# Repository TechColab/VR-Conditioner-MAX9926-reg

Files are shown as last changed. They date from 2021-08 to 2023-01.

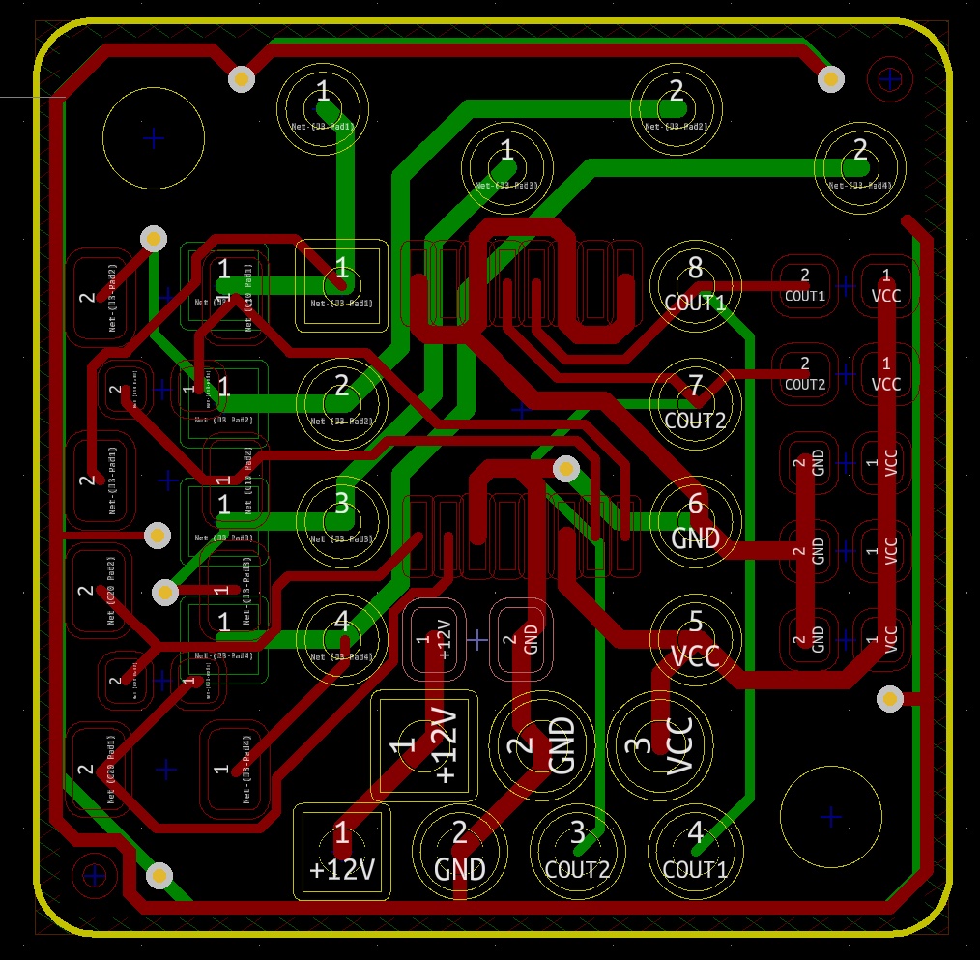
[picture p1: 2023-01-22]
PCB-Tracks.jpg

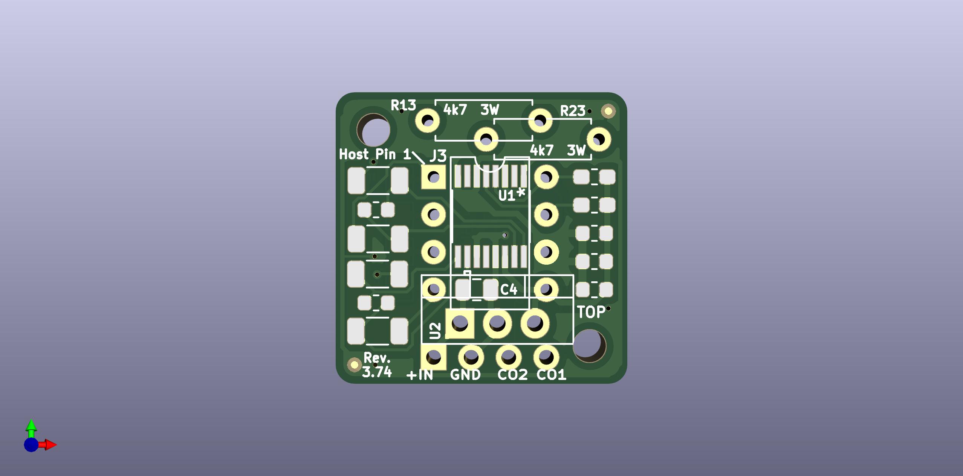
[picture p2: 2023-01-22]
VR-Conditioner-MAX9926+reg-F.jpg

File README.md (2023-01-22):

### 2023-01-22
Most significant change is to correct the Channel 1 polarity of previous version.
In practise everyone seems to try their VR pick-up in both polarities before settling on the best for their set-up.
Tidied the silkscreen a lot to improve readability. Removed component IDs from silkscreen. Still on the FAB layer.
Moved a regulator & edge pin header slightly to make soldering easier.
Re-routed traces from header pins 1 & 2 so that either could be cut if you wanted to mix VR & a piggy-backed opto-isolator.
Also update because KiCAD v6.x seems to have moved a lot of things.

### 2022-09-10
Received a batch of v3.73 boards & bench-tested using 13 year-old Crankshaft Position Sensor 7674201-01 from 2009 BMW F800R 
and a metal 'L' hook screw in a hand drill at about 1000 rpm. All OK on 5V & also on 12V with a TS78L05CT TO-92 regulator.

### 2022-08-14
Replace linear regulator with more robust choice. Move U1 & C4 to make space. Adjust all tracks as required including widening. 
Updated BOM.  I will shortly be ordering a run of these, e-mail if you're interested: TechColab.co.je [at] Gmail.con

### 2022-08-07
Added test-pads which can be used to solder directly when not using socket mount, E.g. when placing the VR conditioner as close as possible to the engine sensors in noisy environments. Improved ground plane shielding & much improved silk screen labelling. Tried to fit an official OpenSource Hardware logo but even the smallest is too big. Update to KiCAD v6.x so 3D renders now without components.  N.B. To be clear, this board is for VR only & does not support an opto-isolator option.

### 2021-02-23
I have not made & tested this design but it is barely changed from the manufacrurers data sheets or other designs.
If you make & test it then please advise.

I'm new to KiCAD so I don't know how to do some things.  Such as how to have an 8-pin set of holes without a 3D chip sitting in it.
Or how to do an 8-pin header in the shape & pin count order of a chip.

### 2021-02-24
Changed version number to 3.5 so that it reflects relative cronology from previous design.
Renamed this from Notes.txt to README.md & corrected the date above.
Added Comments to schematic, inc. single-sided design allowing 'Letter' postage!
Updated BOM in schematic to reflect readily available parts found on OctoPart.

### 2021-04-22
Goal: give the left 6 passive components some space from the edge.
Increase size/power of some SMT resistors where suggested.
Re-route COUT1 from DIP.8 to SIL.4 in green so no signal traces are by the edge.
Shift right 5 components slightly right.
Shift DIP, chip & hidden cap slightly right.
Shift left 6 components slightly right.
Re-route left 6 components to avoid side swapping.
Ensure GND plane encircles everything with a via in each corner.
Tidy with some symetry.
Ensure all 'thin' traces are 0.20mm (up from 0.16)

### 2021-08-16
Move to it's own project to reflect that Speeduino main project has dropped all VRs.
Re-applied logical resistor numbering.  Bumped schematic v to 3.7 to match PCB.

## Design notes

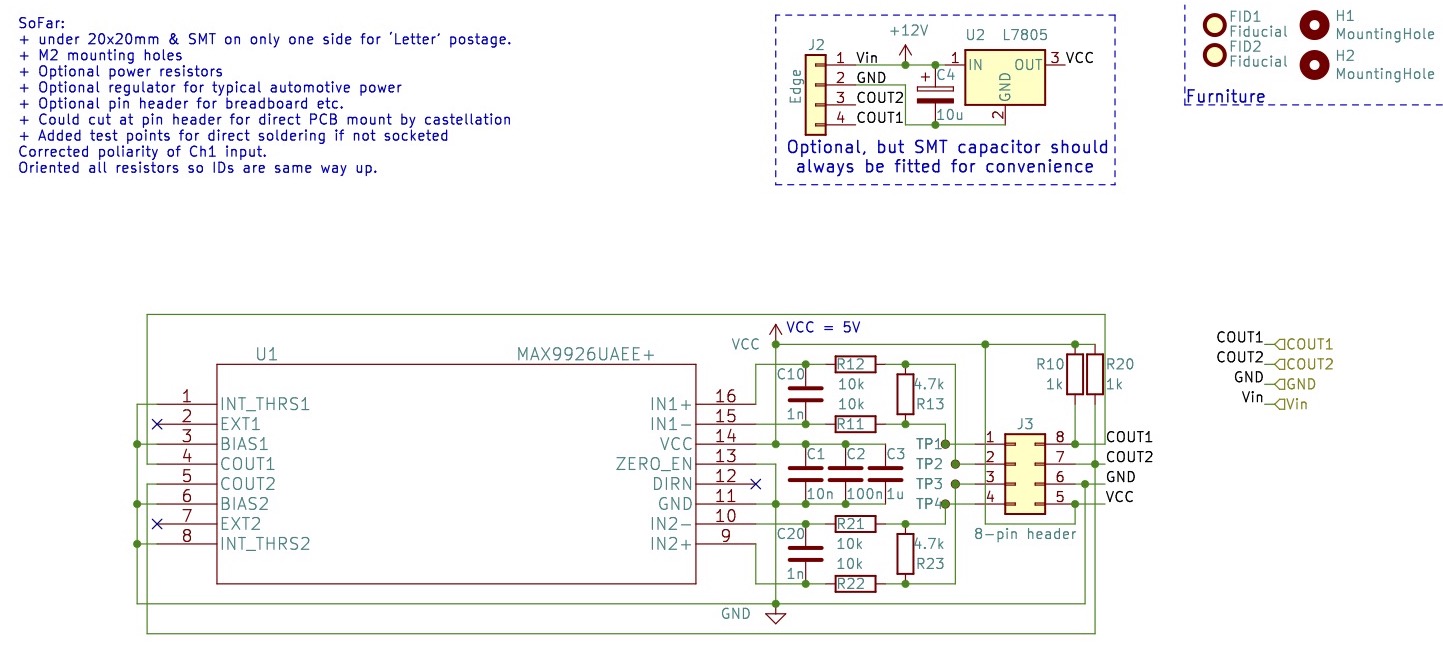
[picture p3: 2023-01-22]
Schematic.jpg

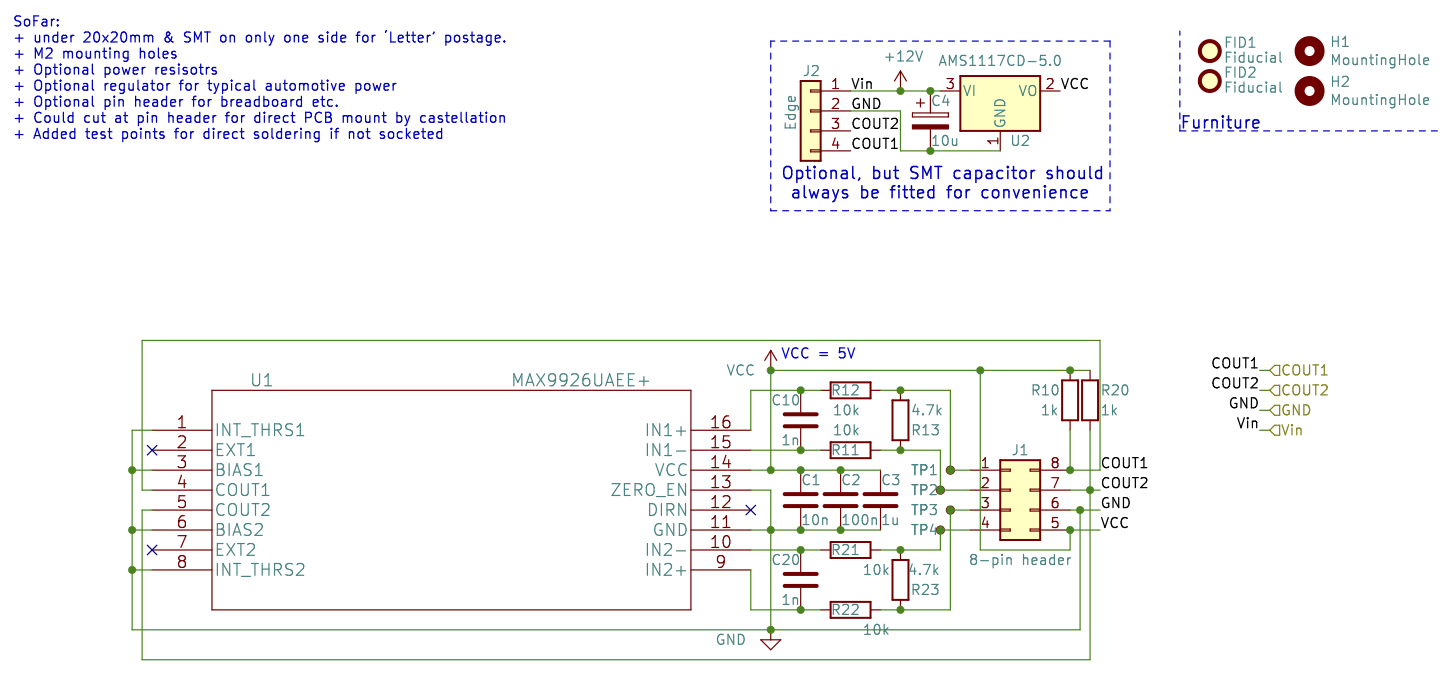
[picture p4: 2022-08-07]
Schematic.png

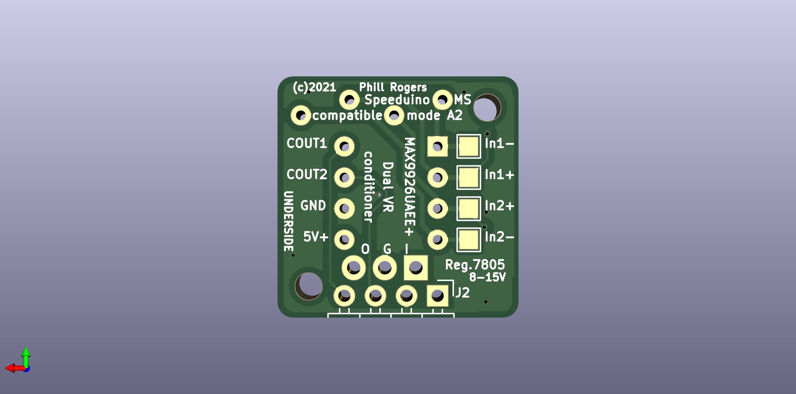
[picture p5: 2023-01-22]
VR-Conditioner-MAX9926+reg-B.jpg

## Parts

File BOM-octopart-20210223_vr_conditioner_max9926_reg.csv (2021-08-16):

Qty | Line Item | Manufacturer | MPN | Octopart URL | Schematic Reference | Internal Part Number | Description | Lifecycle Status | Lead Time | RoHS | Total Qty (@ Batch Size: 1) | SKU | SKU | SKU | SKU | Packaging | Packaging | Packaging | Packaging | Unit Price (@ Batch Size: 1) | Unit Price (@ Batch Size: 1) | Unit Price (@ Batch Size: 1) | Unit Price (@ Batch Size: 1) | In Stock | In Stock | In Stock | In Stock | MOQ | MOQ | MOQ | MOQ | URL | URL | URL | URL | Distributor [Lowest Price (Overall)] | SKU [Lowest Price (Overall)] | Packaging [Lowest Price (Overall)] | Unit Price (@ Batch Size: 1) [Lowest Price (Overall)] | Line Total [Lowest Price (Overall)] | Batch Total [Lowest Price (Overall)] | In Stock [Lowest Price (Overall)] | MOQ [Lowest Price (Overall)] | URL [Lowest Price (Overall)] | Notes
 |  |  |  |  |  |  |  |  |  |  |  | Digi-Key | Future Electronics | Mouser | RS Components | Digi-Key | Future Electronics | Mouser | RS Components | Digi-Key | Future Electronics | Mouser | RS Components | Digi-Key | Future Electronics | Mouser | RS Components | Digi-Key | Future Electronics | Mouser | RS Components | Digi-Key | Future Electronics | Mouser | RS Components
1 | GRM1857U1A103JA44D | Murata | GRM1857U1A103JA44D | https://octopart.com/grm1857u1a103ja44d-murata-17754272 |  |  |  | Production (Last Updated: 2 weeks ago) | 23w | Compliant | 1 | 490-8269-1-ND | 1117428 | 81-GRM1857U1A103JA4D |  | Cut Tape | Cut Tape | Tape & Reel |  | 0.15622662 | 0.159777225 | 0.17753025 |  | 24842 | 8000 | 6230 |  | 1 | 1 | 1 |  | https://octopart.com/click/track?country=JE&ct=offers&ppid=17754272&sid=459&sig=0a4da8a&vpid=88253296&ai4=706 | https://octopart.com/click/track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 | https://octopart.com/click/track?country=JE&ct=offers&ppid=17754272&sid=2401&sig=0942290&vpid=37708184&ai4=706 |  | Arrow Electronics | GRM1857U1A103JA44D | Cut Tape | 0.1077253557 | 0.1077253557 | 0.1077253557 | 1 | 1 | https://octopart.com/click/track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
2 | CRCW06031K00FKEAHP | Vishay | CRCW06031K00FKEAHP | https://octopart.com/crcw06031k00fkeahp-vishay-42634138 |  |  |  |  | 24w | Compliant | 2 | 541-1.00KSCT-ND | 7110920 | 71-CRCW06031K00FKEAH | 8206776 | Cut Tape | Cut Tape | Tape & Reel |  | 0.12072057000000001 | 0.104387787 | 0.12072057000000001 |  | 205723 | 16210 | 69615 | 2125 | 1 | 1 | 1 | 25 | https://octopart.com/click/track?country=JE&ct=offers&ppid=42634138&sid=459&sig=04dce86&vpid=115677389&ai4=706 | https://octopart.com/click/track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 | https://octopart.com/click/track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 | https://octopart.com/click/track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 | Farnell | 1738905 | Cut Tape | 0.0412 | 0.0824 | 0.0824 | 32145 | 1 | https://octopart.com/click/track?country=JE&ct=offers&ppid=42634138&sid=819&sig=05fe86e&vpid=250080956&ai4=706
4 | CRCW060310K0FKEAHP | Vishay | CRCW060310K0FKEAHP | https://octopart.com/crcw060310k0fkeahp-vishay-42634028 |  |  |  |  | 24w | Compliant | 4 | 541-10.0KSCT-ND | 6103726 | 71-CRCW060310K0FKEAH | 8206742 | Cut Tape | Cut Tape | Tape & Reel |  | 0.12072057000000001 | 0.104387787 | 0.12072057000000001 |  | 84206 | 65036 | 112208 | 2550 | 1 | 1 | 1 | 25 | https://octopart.com/click/track?country=JE&ct=offers&ppid=42634028&sid=459&sig=0828559&vpid=115262443&ai4=706 | https://octopart.com/click/track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 | https://octopart.com/click/track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 | https://octopart.com/click/track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 | Newark | 68R2991 | Cut Tape | 0.017753025000000002 | 0.07101210000000001 | 0.07101210000000001 | 10760 | 1 | https://octopart.com/click/track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
1 | MAX9926UAEE+ | Maxim Integrated | MAX9926UAEE+ | https://octopart.com/max9926uaee%2B-maxim+integrated-42513566 |  |  |  | Production (Last Updated: 1 month ago) | 6w | Compliant | 1 | MAX9926UAEE+-ND | 3086399 | 700-MAX9926UAEE | 1901381 | Tube | Tube | Tube |  | 4.86432885 |  | 6.44789868 | 4.98 | 1069 | 100 | 299 | 0 | 1 | 100 | 1 | 1 | https://octopart.com/click/track?country=JE&ct=offers&ppid=42513566&sid=459&sig=0fd0a9b&vpid=115650128&ai4=706 | https://octopart.com/click/track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 | https://octopart.com/click/track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 | https://octopart.com/click/track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 | Newark | 73Y6635 |  | 4.73650707 | 4.73650707 | 4.73650707 | 10 | 1 | https://octopart.com/click/track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
1 | GCM188R71C105KA64D | Murata | GCM188R71C105KA64D | https://octopart.com/gcm188r71c105ka64d-murata-13159598 |  |  |  | Production (Last Updated: 2 weeks ago) | 27w | Compliant | 1 | 490-5241-1-ND | 7025260 | 81-GCM188R71C105K64D | 7900562 | Cut Tape | Cut Tape | Tape & Reel |  | 0.15622662 | 0.152676015 | 0.15622662 |  | 272359 | 2118 | 0 | 11400 | 1 | 1 | 1 | 25 | https://octopart.com/click/track?country=JE&ct=offers&ppid=13159598&sid=459&sig=065a155&vpid=34232850&ai4=706 | https://octopart.com/click/track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 | https://octopart.com/click/track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 | https://octopart.com/click/track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 | Arrow Electronics | GCM188R71C105KA64D | Cut Tape | 0.1297391067 | 0.1297391067 | 0.1297391067 | 52386 | 1 | https://octopart.com/click/track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
1 | GRM21BR61E106MA73L | Murata | GRM21BR61E106MA73L | https://octopart.com/grm21br61e106ma73l-murata-46693545 |  |  |  | Production (Last Updated: 2 weeks ago) | 29w | Compliant | 1 | 490-10748-1-ND | 3104124 | 81-GRM21BR61E106MA3L | 1726799 | Cut Tape | Cut Tape | Tape & Reel |  | 0.17753025 | 0.173979645 | 0.18463146 |  | 169134 | 22568 | 63443 | 700 | 1 | 1 | 1 | 50 | https://octopart.com/click/track?country=JE&ct=offers&ppid=46693545&sid=459&sig=0e7381d&vpid=210890997&ai4=706 | https://octopart.com/click/track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 | https://octopart.com/click/track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 | https://octopart.com/click/track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 | Arrow Electronics | GRM21BR61E106MA73L | Cut Tape | 0.1290289857 | 0.1290289857 | 0.1290289857 | 18282 | 1 | https://octopart.com/click/track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
2 | GRM1885C1H102JA01D | Murata | GRM1885C1H102JA01D | https://octopart.com/grm1885c1h102ja01d-murata-196169 |  |  |  | Production (Last Updated: 2 weeks ago) | 29w | Compliant | 2 | 490-1451-1-ND | 5104092 | 81-GRM39C102J50 | 7235795 | Cut Tape | Cut Tape | Tape & Reel |  | 0.07101210000000001 | 0.0102257424 | 0.07101210000000001 |  | 0 | 2890 | 845260 | 5800 | 1 | 1 | 1 | 200 | https://octopart.com/click/track?c=1&country=JE&ct=offers&ppid=196169&sid=459&sig=0c67cea&vpid=1086114&ai4=706 | https://octopart.com/click/track?country=JE&ct=offers&ppid=196169&sid=2454&sig=06c4930&vpid=495870445&ai4=706 | https://octopart.com/click/track?country=JE&ct=offers&ppid=196169&sid=2401&sig=0c58fdf&vpid=37712468&ai4=706 | https://octopart.com/click/track?country=JE&ct=offers&ppid=196169&sid=10022&sig=0888f0c&vpid=199072014&ai4=706 | Future Electronics | 5104092 | Cut Tape | 0.0102257424 | 0.0204514848 | 0.0204514848 | 2890 | 1 | https://octopart.com/click/track?country=JE&ct=offers&ppid=196169&sid=2454&sig=06c4930&vpid=495870445&ai4=706
1 | GCJ188R71C104KA01D | Murata | GCJ188R71C104KA01D | https://octopart.com/gcj188r71c104ka01d-murata-21222040 |  |  |  | Production (Last Updated: 2 weeks ago) | 27w | Compliant | 1 | 490-5796-1-ND | 6113232 | 81-GCJ188R71C104KA1D |  | Cut Tape | Cut Tape | Tape & Reel |  | 0.19173267000000002 | 0.188182065 | 0.17042904 |  | 38484 | 1000 | 178383 |  | 1 | 1 | 1 |  | https://octopart.com/click/track?country=JE&ct=offers&ppid=21222040&sid=459&sig=0e464ea&vpid=44469513&ai4=706 | https://octopart.com/click/track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 | https://octopart.com/click/track?country=JE&ct=offers&ppid=21222040&sid=2401&sig=02bb046&vpid=47654983&ai4=706 |  | Mouser | 81-GCJ188R71C104KA1D | Tape & Reel | 0.17042904 | 0.17042904 | 0.17042904 | 178383 | 1 | https://octopart.com/click/track?country=JE&ct=offers&ppid=21222040&sid=2401&sig=02bb046&vpid=47654983&ai4=706

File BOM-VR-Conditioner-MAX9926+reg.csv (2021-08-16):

Reference | Value | Footprint | Datasheet | Critical | Description | MFG Name | MFG Part Num | Package JEDEC ID
FID1 | Fiducial | Fiducial:Fiducial_0.5mm_Mask1mm | ~
FID2 | Fiducial | Fiducial:Fiducial_0.5mm_Mask1mm | ~
U1 | MAX9926UAEE+ | MAX9926UAEE+:MAX9926UAEE&plus_ | https://datasheet.octopart.com/MAX9926UAEE%2B-Maxim-Integrated-datasheet-11046290.pdf | Yes | MAX9926 Series 10 mA Differential Input Logic Output Sensor Interface -SSOP-16 | Maxim Integrated | MAX9926UAEE+ | SSOP-16
C1 | 10n | Capacitor_SMD:C_0603_1608Metric | ~ |  | 10 V ±5% Tolerance U2J Multilayer Ceramic Capacitor | Murata Murata | GRM1857U1A103JA44D | 0603_1608Metric
C2 | 100n | Capacitor_SMD:C_0603_1608Metric | ~ |  | Ceramic 0.1uF 16V X7R 10% Pad SMD 0603 Soft Termination 125C Automotive T/R | Murata | GCJ188R71C104KA01D | 0603_1608Metric
C3 | 1u | Capacitor_SMD:C_0603_1608Metric | ~ |  | 16V ±10% Tolerance X7R Surface Mount Multilayer Ceramic Capacitor | Murata | GCM188R71C105KA64D | 0603_1608Metric
C20 | 1n | Capacitor_SMD:C_0603_1608Metric | ~ |  | 1000 pF 50 V ±5 % Tolerance C0G SMT Multilayer Ceramic Capacitor | Murata | GRM1885C1H102JA01D | 0603_1608Metric
C10 | 1n | Capacitor_SMD:C_0603_1608Metric | ~ |  | 1000 pF 50 V ±5 % Tolerance C0G SMT Multilayer Ceramic Capacitor | Murata | GRM1885C1H102JA01D | 0603_1608Metric
R22 | 10k | Resistor_SMD:R_0603_1608Metric_Pad1.05x0.95mm_HandSolder | ~ |  |  | Yageo | RC1206FR-7W10KL | Resistor_SMD:R_1206_3216Metric
R21 | 10k | Resistor_SMD:R_0603_1608Metric_Pad1.05x0.95mm_HandSolder | ~ |  |  | Yageo | RC1206FR-7W10KL | Resistor_SMD:R_1206_3216Metric
R11 | 10k | Resistor_SMD:R_0603_1608Metric_Pad1.05x0.95mm_HandSolder | ~ |  |  | Yageo | RC1206FR-7W10KL | Resistor_SMD:R_1206_3216Metric
R12 | 10k | Resistor_SMD:R_0603_1608Metric_Pad1.05x0.95mm_HandSolder | ~ |  |  | Yageo | RC1206FR-7W10KL | Resistor_SMD:R_1206_3216Metric
R13 | 4.7k | Resistor_THT:R_Axial_DIN0207_L6.3mm_D2.5mm_P7.62mm_Horizontal | ~ | DoNoPlace. User option | 3W, 5%
J1 | 8-pin header | Package_DIP:DIP-8_W7.62mm | ~
R20 | 1k | Resistor_SMD:R_0603_1608Metric_Pad1.05x0.95mm_HandSolder | ~ |  | Thick Film; +/-1% 0.2W | Vishay | CRCW06031K00FKEAHP | 0603_1608Metric
R10 | 1k | Resistor_SMD:R_0603_1608Metric_Pad1.05x0.95mm_HandSolder | ~ |  | Thick Film; +/-1% 0.2W | Vishay | CRCW06031K00FKEAHP | 0603_1608Metric
H1 | MountingHole | MountingHole:MountingHole_2.2mm_M2 | ~
H2 | MountingHole | MountingHole:MountingHole_2.2mm_M2 | ~
C4 | 10u | Capacitor_SMD:C_0805_2012Metric | ~ |  | 25 V 10 uF ±20% Tolerance X5R Multilayer Ceramic Capacitor | Murata | GRM21BR61E106MA73L | 0805_2012Metric
R23 | 4.7k | Resistor_THT:R_Axial_DIN0207_L6.3mm_D2.5mm_P7.62mm_Horizontal | ~ | DoNoPlace. User option | 3W, 5%
U2 | AMS1117CD-5.0 | Package_TO_SOT_THT:TO-92_Inline_Wide | http://www.advanced-monolithic.com/pdf/ds1117.pdf | DoNoPlace. User option | 1A Low Dropout Voltage Regulator | Advanced Monolithic Systems | AMS1117-5.0 | TO92 inline wide
J2 | Edge | Connector_PinHeader_2.54mm:PinHeader_1x04_P2.54mm_Horizontal | ~ | DoNoPlace. User option

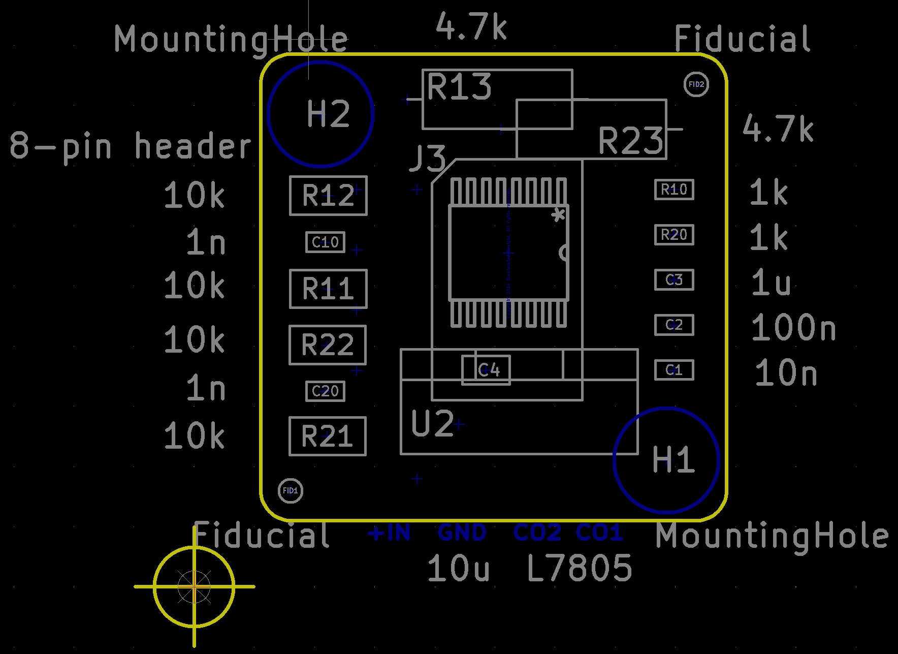
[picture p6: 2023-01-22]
Component layout.jpg

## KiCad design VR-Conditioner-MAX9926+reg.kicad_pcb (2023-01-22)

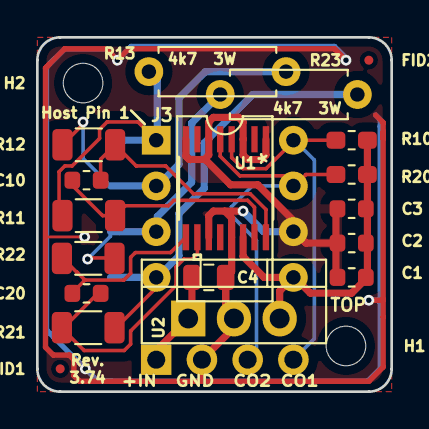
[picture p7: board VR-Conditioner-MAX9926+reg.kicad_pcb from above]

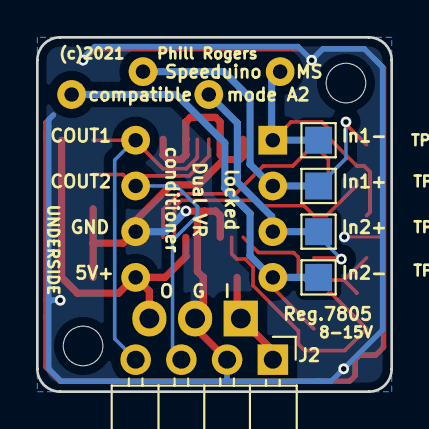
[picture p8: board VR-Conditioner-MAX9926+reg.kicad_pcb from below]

Board: 2 copper layers, 19.7 x 19.7 mm, 26 parts (5 on the bottom side), 13 nets.

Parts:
C1: 10n; C_0603_1608Metric
C2: 100n; C_0603_1608Metric
C3: 1u; C_0603_1608Metric
C4: 10u; C_0805_2012Metric
C10, C20: 1n; C_0603_1608Metric
FID1, FID2: Fiducial; Fiducial_0.5mm_Mask1mm
H1, H2: MountingHole; MountingHole_2.2mm_M2
J2: Edge; PinHeader_1x04_P2.54mm_Horizontal
J3: 8-pin header; DIP-8_W7.62mm
R10, R20: 1k; R_0603_1608Metric_Pad1.05x0.95mm_HandSolder
R11, R12, R21, R22: 10k; R_1206_3216Metric
R13, R23: 4.7k; R_Axial_DIN0207_L6.3mm_D2.5mm_P7.62mm_Horizontal
TP1, TP2, TP3, TP4: TP; TestPoint_Pad_1.5x1.5mm
U1: locked; MAX9926UAEE&plus_
U2: L7805; TO-220-3_Vertical

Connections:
+12V: C4.1, J2.1, U2.1 (IN)
/COUT1: J2.4, J3.8, R10.2, U1.4 (COUT1)
/COUT2: J2.3, J3.7, R20.2, U1.5 (COUT2)
GND: C1.2, C2.2, C3.2, C4.2, J2.2, J3.6, U1.1 (INT_THRS1), U1.3 (BIAS1), U1.6 (BIAS2), U1.8 (INT_THRS2), U1.11 (GND), U1.13 (ZERO_EN), U2.2 (GND)
unnamed: C10.1, R12.1, U1.16 (IN1+)
unnamed: C10.2, R11.1, U1.15 (IN1-)
unnamed: C20.1, R21.2, U1.10 (IN2-)
unnamed: C20.2, R22.2, U1.9 (IN2+)
unnamed: J3.1, R11.2, R13.1, TP1.1
unnamed: J3.2, R12.2, R13.2, TP2.1
unnamed: J3.3, R22.1, R23.1, TP3.1
unnamed: J3.4, R21.1, R23.2, TP4.1
VCC: C1.1, C2.1, C3.1, J3.5, R10.1, R20.1, U1.14 (VCC), U2.3 (OUT)

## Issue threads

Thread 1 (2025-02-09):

Undocumented new board version V4

yugokoral, 2025-02-09:
Hello team. I was looking for the latest version of a VR conditioner and i came across the version 4 on ebay. I can not find any official nor unofficial documentation about that PCB-assembly. Is this an unofficial release or maybe some DIY project?
Here is a link:
https://www.ebay.co.uk/itm/156438844270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

Thank you for more info :D

TechColab, 2025-02-10:
At a glance it looks slightly different from my last version.  A cap has moved & a couple of resistors changed size (maybe an issue). I will have a better look in a bit. Sent from my iPhoneOn 9 Feb 2025, at 10:14, yugokoral ***@***.***> wrote:
Hello team. I was looking for the latest version of a VR conditioner and i came across the version 4 on ebay. I can not find any official nor unofficial documentation about that PCB-assembly. Is this an unofficial release or maybe some DIY project?
Here is a link:
https://www.ebay.co.uk/itm/156438844270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
Thank you for more info :D

—Reply to this email directly, view it on GitHub, or unsubscribe.You are receiving this because you are subscribed to this thread.Message ID: ***@***.***>

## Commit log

2021-08-16 bump thin trace to 0.2mm
    [VR-Conditioner-MAX9926+reg-B_Cu.gbl, VR-Conditioner-MAX9926+reg-B_Mask.gbs, VR-Conditioner-MAX9926+reg-B_Paste.gbp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]
2022-08-07 Improve silk screen labeling & ground plane. Added solder pads.
    [VR-Conditioner-MAX9926+reg-B_Cu.gbl, VR-Conditioner-MAX9926+reg-B_Mask.gbs, VR-Conditioner-MAX9926+reg-B_Silkscreen.gbo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]
2022-08-07 Remove silk text from test point solder pads.
    [VR-Conditioner-MAX9926+reg-B_Cu.gbl, VR-Conditioner-MAX9926+reg-B_Mask.gbs, VR-Conditioner-MAX9926+reg-B_Paste.gbp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]
2023-01-22 v3.74 corrects channel 1 polarity, improves silkscreen & makes soldering of PTH bits easier.
    Polarity in previous version not critical as everyone seems to try their pick-up each way anyhow.
    [VR-Conditioner-MAX9926+reg-B_Cu.gbl, VR-Conditioner-MAX9926+reg-B_Fab.gbr, VR-Conditioner-MAX9926+reg-B_Mask.gbs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]

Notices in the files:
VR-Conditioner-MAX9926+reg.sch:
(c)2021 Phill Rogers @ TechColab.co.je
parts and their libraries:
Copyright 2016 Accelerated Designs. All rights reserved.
